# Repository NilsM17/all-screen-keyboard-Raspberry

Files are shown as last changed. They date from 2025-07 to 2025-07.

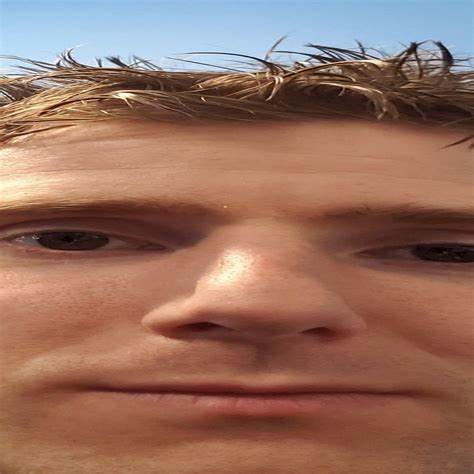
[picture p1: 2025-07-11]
keyboard/img/wide.jpeg

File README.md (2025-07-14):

# Working on Raspberry PI support
Since InkboxSoftware only worked with the Orange PI 5 and that one is way to expensive for my liking i will be working with an Raspberry PI 3 Model B as a replacement because thats what i have on hand (might upgrade to a PI 5 at some point)

# The open source all-screen keyboard
The first open source all-screen keyboard. This repository contains all the digital files used to produce the all-screen keyboard created by Inkbox Software in this video: 

## Future of the all-screen keyboard?
The goal of this project is to create a robust DIY guide for creating an all-screen keyboard. Currentyle there are a couple of software issues that need to be resolved, but more importantly the keys and frames themselves need to be remolded in order to make them more suitable for viewing and mass production. Members of the community are looking towards how to create a cheaper version out of some other material than 3D printed resin. Once we solve these issues, version 2 will be released to the public via this repository. 

## Could I still make my own today?
Well, you probably don't want to. As of today (2025/7/11) the keys are much too tall, and so not all the keys are able to be viewed at once. But for reference here is the list of hardware I used:
* Orange Pi 5 Ultra (any Orange Pi 5 could be a drop in replacement, well, you may have to change which pins you use)
* PCB found in this project's PCB folder
* Top Shell and keys printed in transparent resin
* Bottom shell printed in regular PLA (available as a single piece or multiple parts for printing at home)

Currently start up requires three steps, starting the python program, setting the bluetooth advertisement appearance, and then running the main keyboard program. 

### To enable SPI on the Orange Pi 5:

open **/boot/extlinux/extlinux.conf**

Add the following text
```
FDTOVERLAYS /dtbs/rockchip/overlay/rk3588-spi0-m2-cs0-cs1-spidev.dtbo
/dtbs/rockchip/overlay/rk3588-spi1-m1-cs0-spidev.dtbo
/dtbs/rockchip/overlay/rk3588-spi4-m2-cs0-spidev.dtbo
```

### Running the bluetooth python program:
Ensure you have the proper dependencies installed
```
cd keyboard
make py
```

### Starting bluetooth:
Setting the appearance to 961 will have the Pi show up as a keyboard. 
```
bluetoothctl 
discoverable on
pairable on
advertise on
menu advertise
appearance 961
```

### Starting the main keyboard program
Navigate to the directory
To build the program for the first time run
```
make build
```
Then run with
```
make run
```

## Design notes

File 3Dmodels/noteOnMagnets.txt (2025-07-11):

Magnet hole size notes:

magnets used are 5.0mm in diameter, but to fit them in plastic holes:
	5.2mm for tight fit (diameter)
	5.25 for a bit looser
	anything smaller and they won't go in
	anything larger and they fall out (5.3 sits well, but will fall out with a shake)
	recommend to use 5.25mm diameter holes
depth of hole should be 0.25mm + the height of the magnet

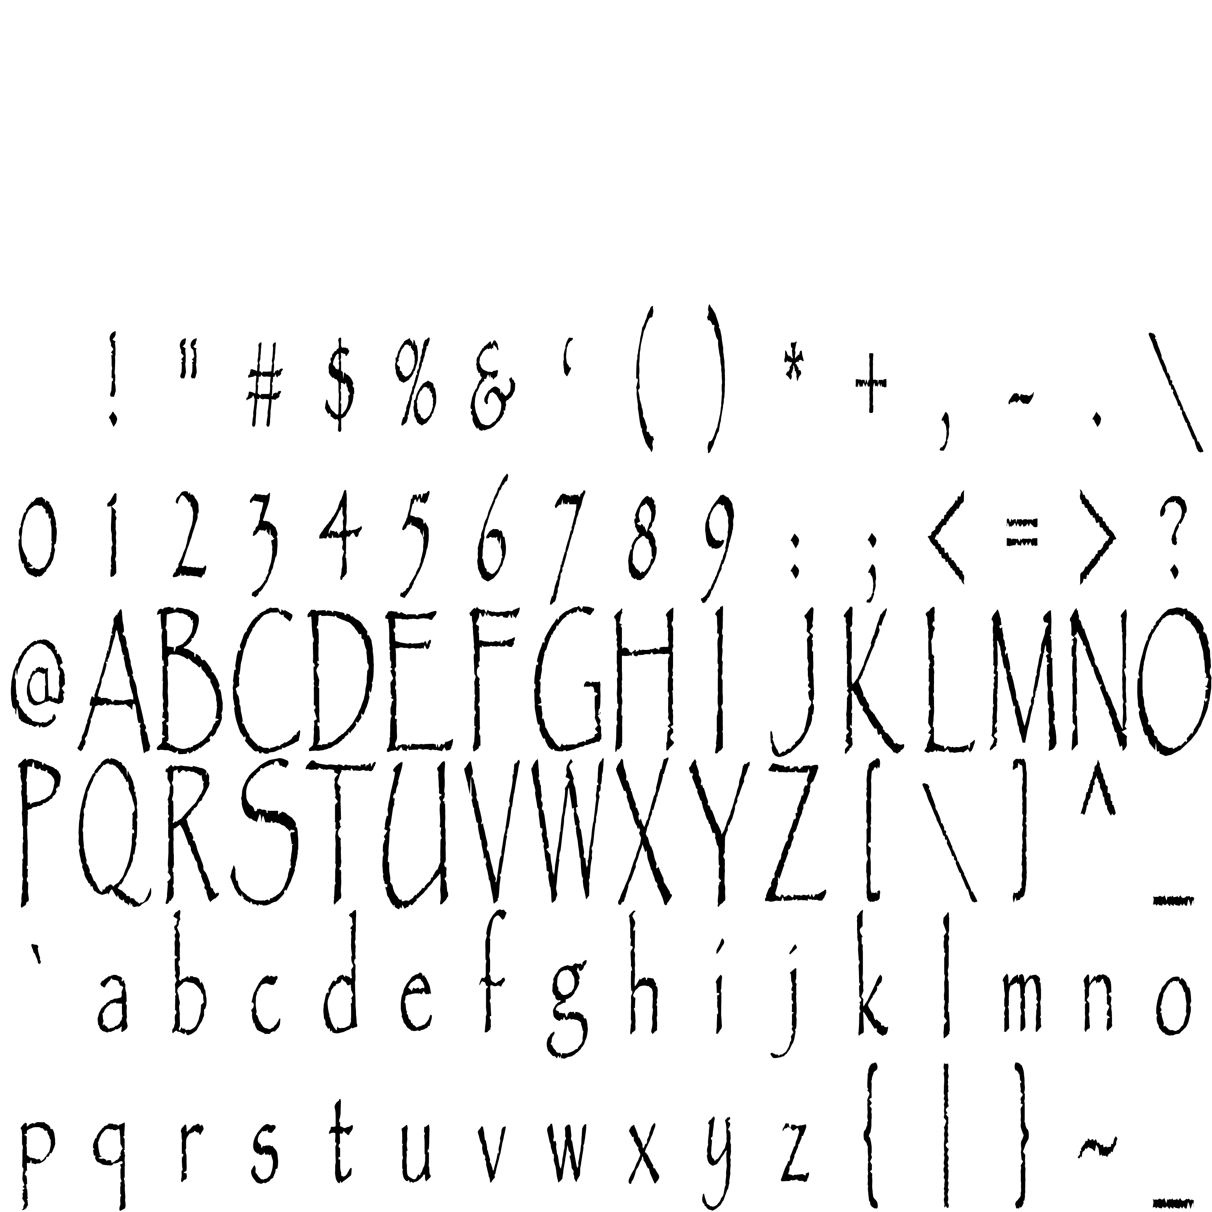
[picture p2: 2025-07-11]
keyboard/img/font2.png

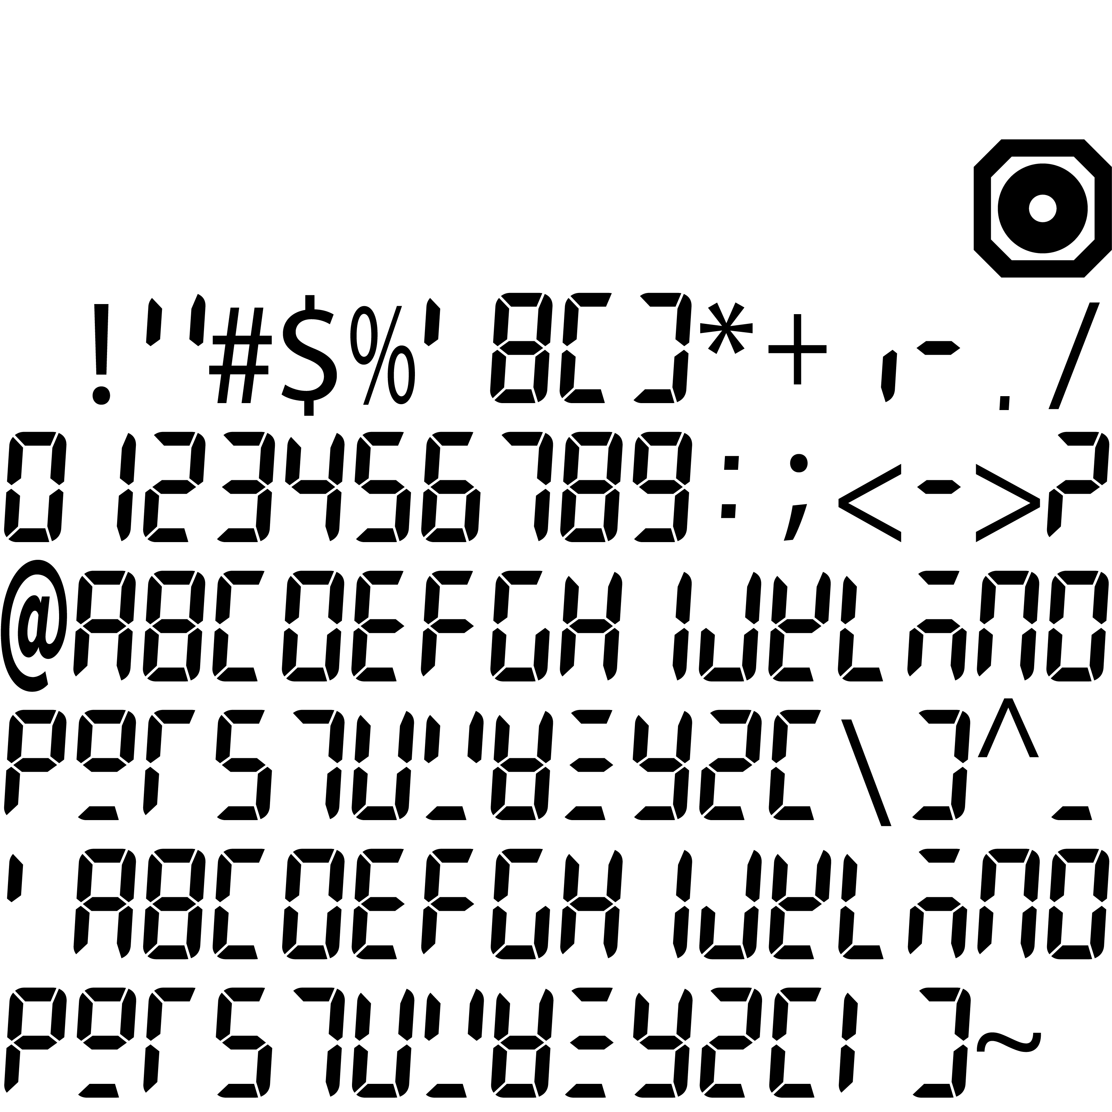
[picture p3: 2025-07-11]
keyboard/img/font.png

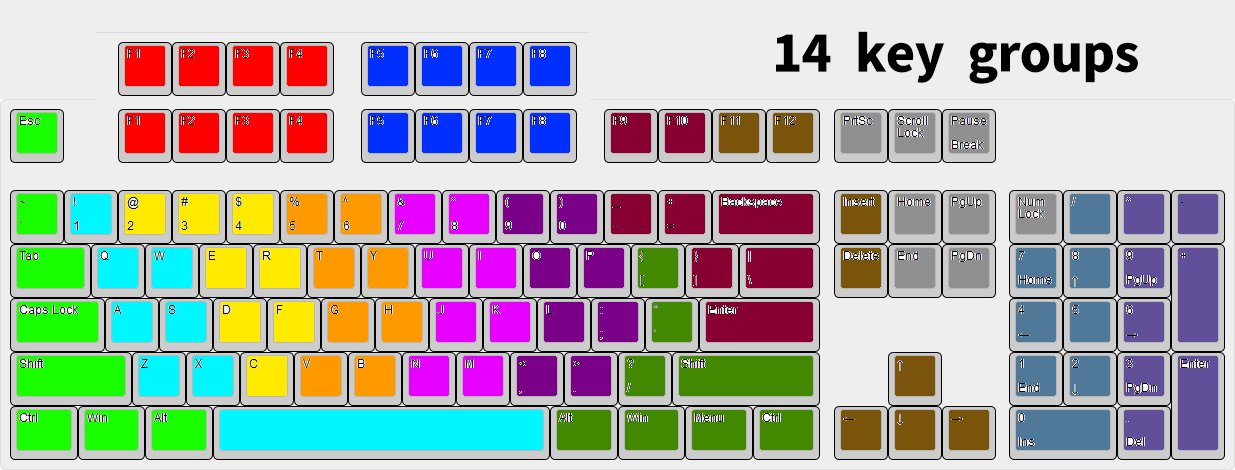
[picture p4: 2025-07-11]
PCB/keyboard-KiCad/keyGroupings.png

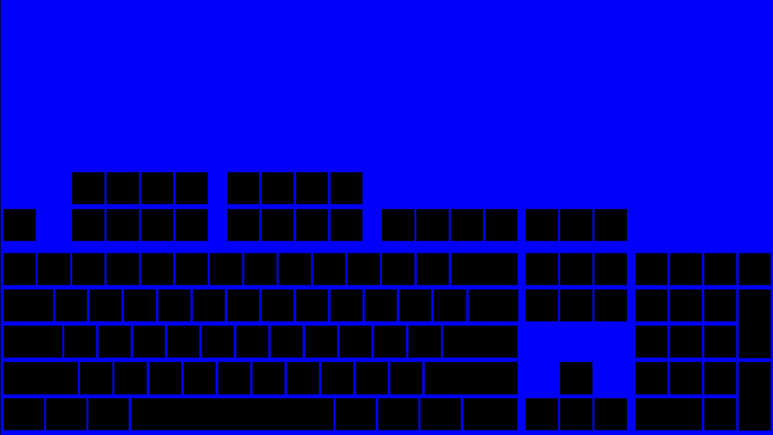
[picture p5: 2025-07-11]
reference images/blank layout.png

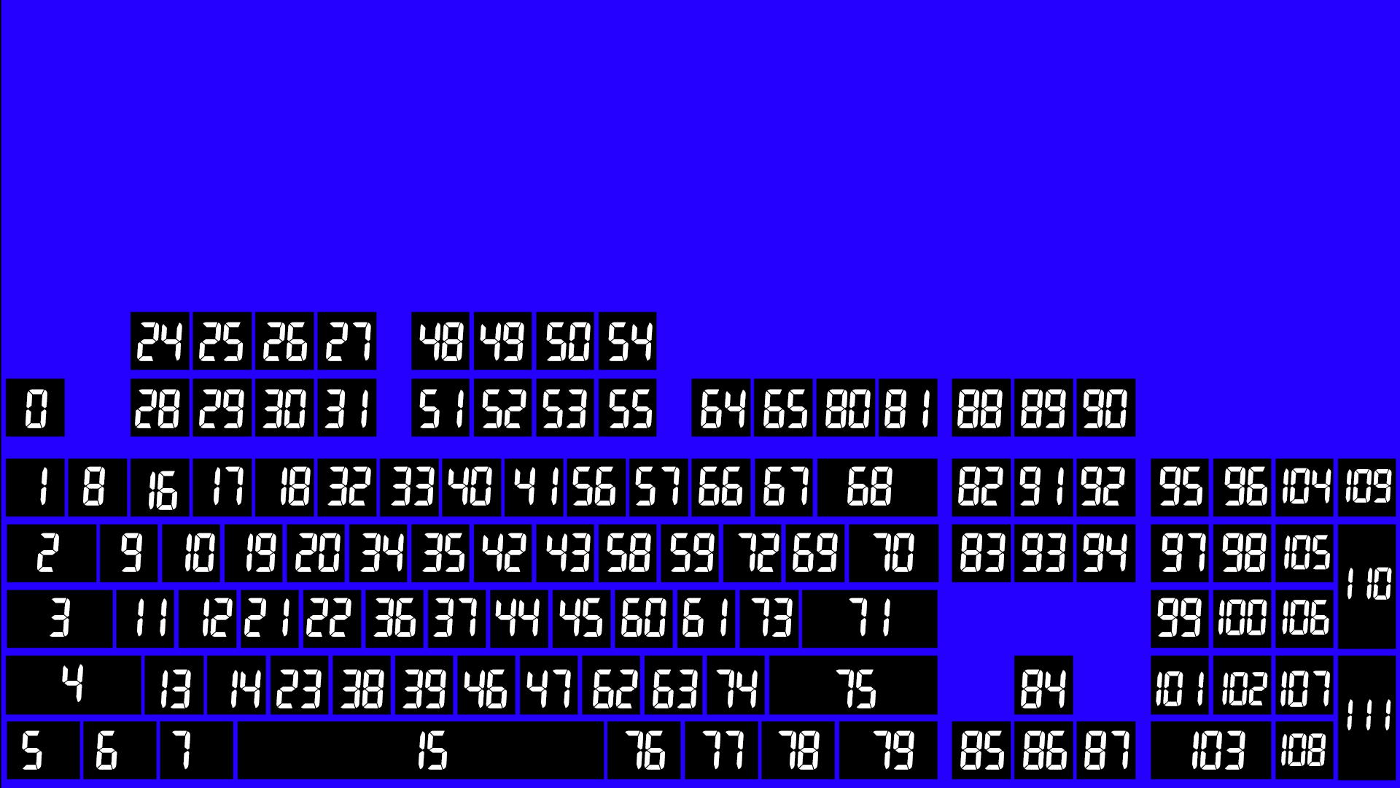
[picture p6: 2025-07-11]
reference images/layout.png

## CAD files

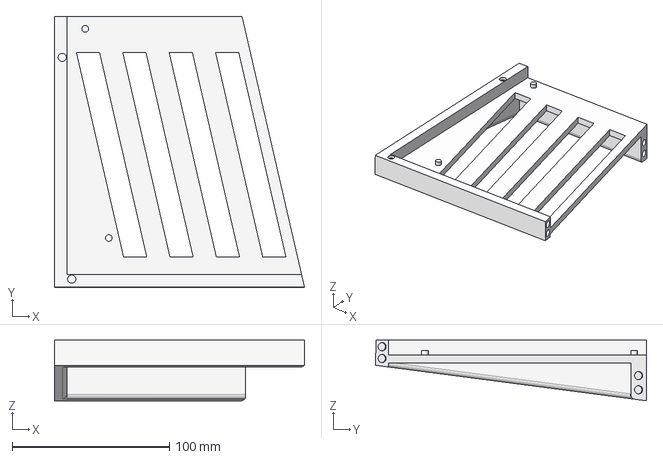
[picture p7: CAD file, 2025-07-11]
3Dmodels/case - multiple pieces/case0-0.step
159.1 x 172.3 x 38.5 mm

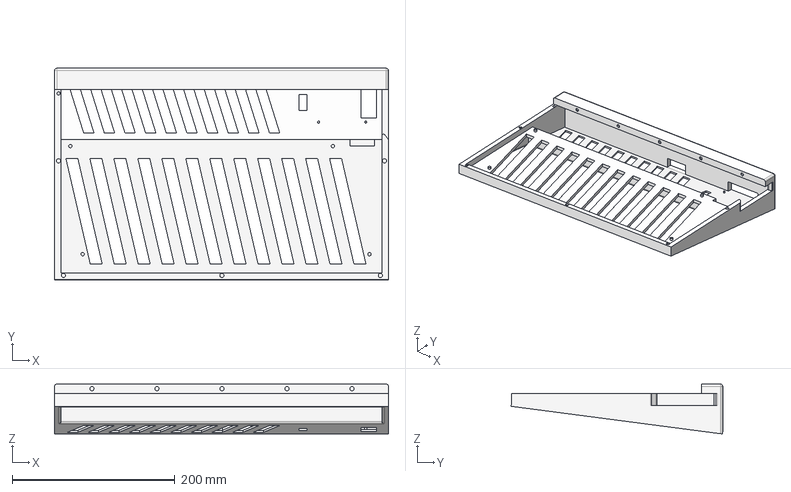
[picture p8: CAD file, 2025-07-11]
3Dmodels/case_onePiece.step
411.0 x 260.3 x 61.5 mm

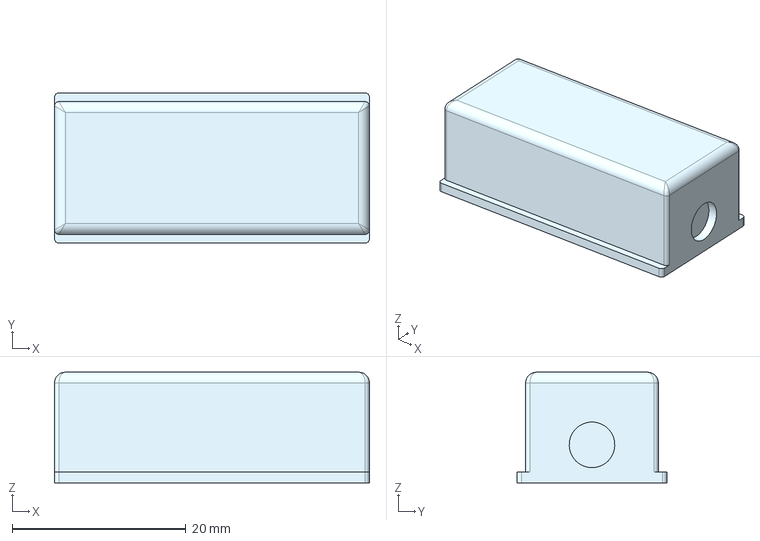
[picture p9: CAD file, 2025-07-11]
3Dmodels/individualkeys/key37.step
36.3 x 17.3 x 12.8 mm

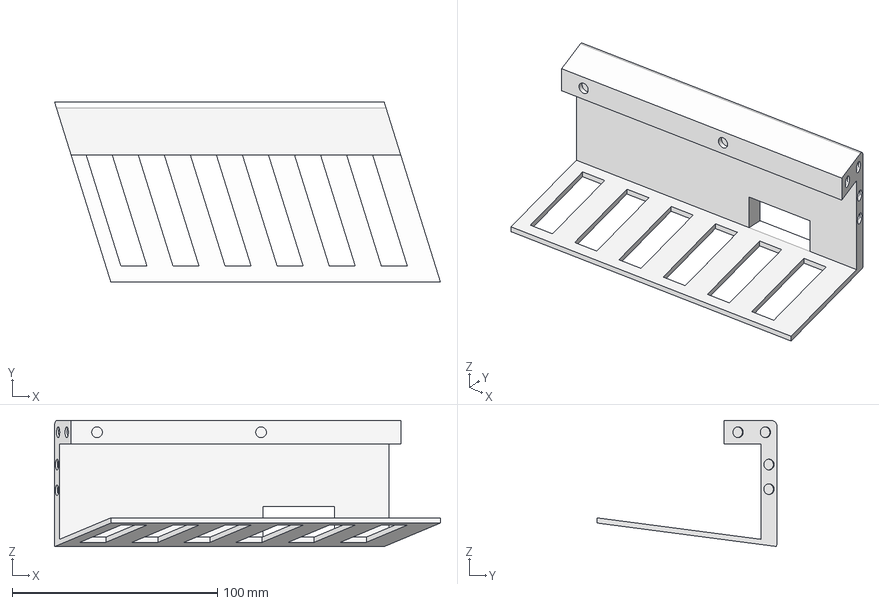
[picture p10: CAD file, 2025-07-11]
3Dmodels/case - multiple pieces/case1-1.step
188.2 x 88.0 x 61.5 mm

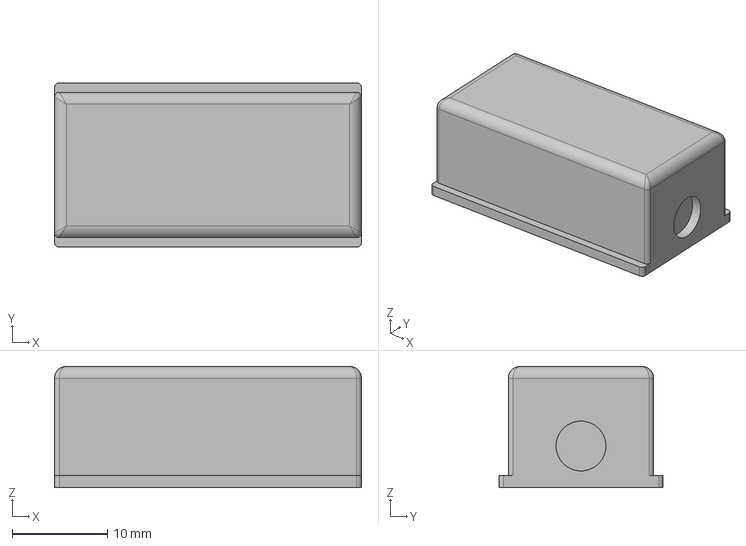
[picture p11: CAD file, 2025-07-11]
3Dmodels/individualkeys/key33.step
32.3 x 17.3 x 12.8 mm

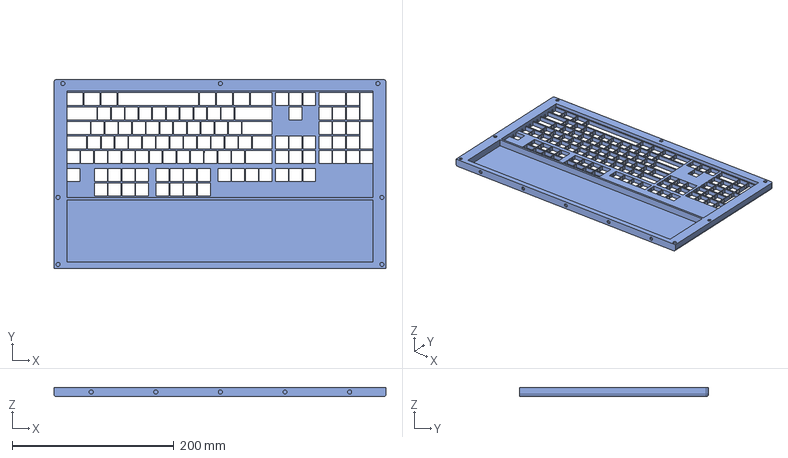
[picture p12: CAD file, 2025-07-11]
3Dmodels/topShell.step
411.0 x 234.0 x 11.5 mm

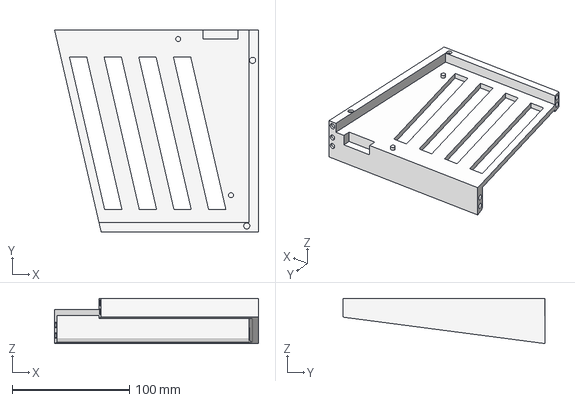
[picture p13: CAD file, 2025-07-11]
3Dmodels/case - multiple pieces/case0-2.step
173.7 x 172.3 x 38.5 mm

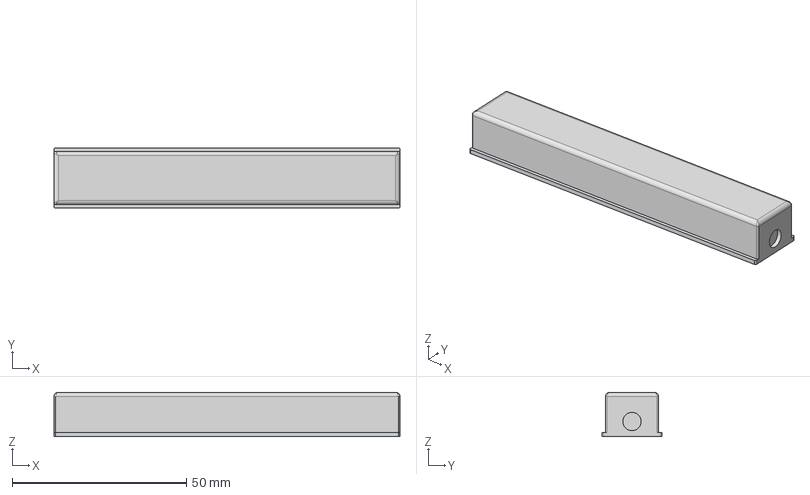
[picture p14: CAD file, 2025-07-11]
3Dmodels/individualkeys/keySpace.step
99.3 x 17.3 x 12.8 mm

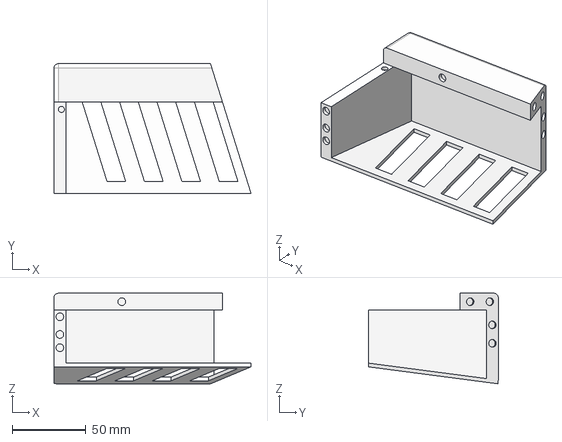
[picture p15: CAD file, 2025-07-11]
3Dmodels/case - multiple pieces/case1-0.step
133.8 x 88.0 x 61.5 mm

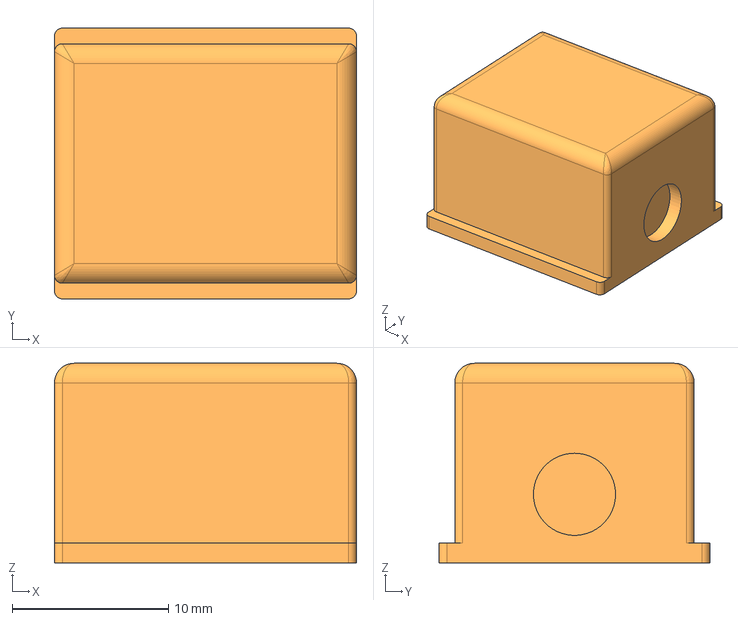
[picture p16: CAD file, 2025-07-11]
3Dmodels/individualkeys/key20.step
19.3 x 17.3 x 12.8 mm

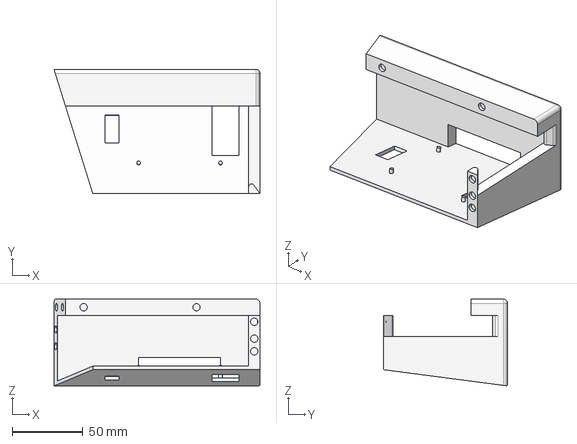
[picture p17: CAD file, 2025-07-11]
3Dmodels/case - multiple pieces/case1-2.step
146.0 x 88.0 x 61.5 mm

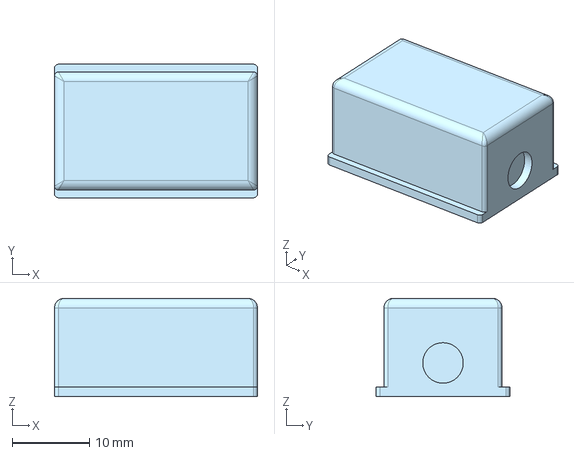
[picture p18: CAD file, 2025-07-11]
3Dmodels/individualkeys/key27.step
26.3 x 17.3 x 12.8 mm

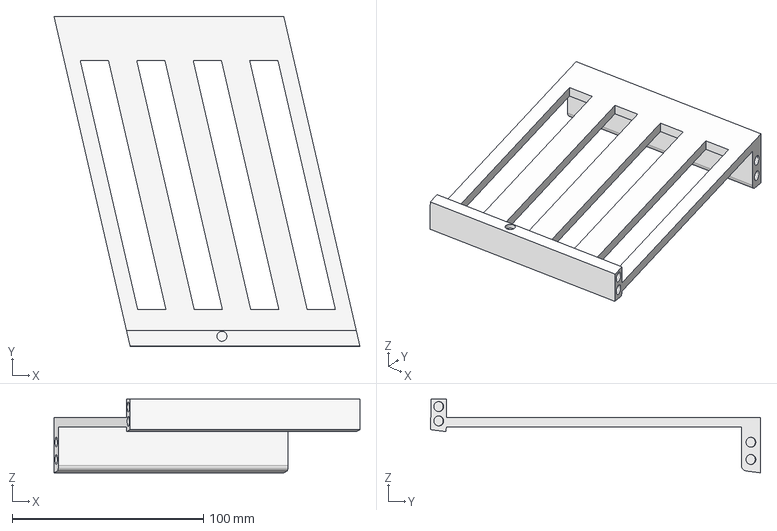
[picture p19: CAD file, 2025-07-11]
3Dmodels/case - multiple pieces/case0-1.step
159.8 x 172.3 x 38.5 mm

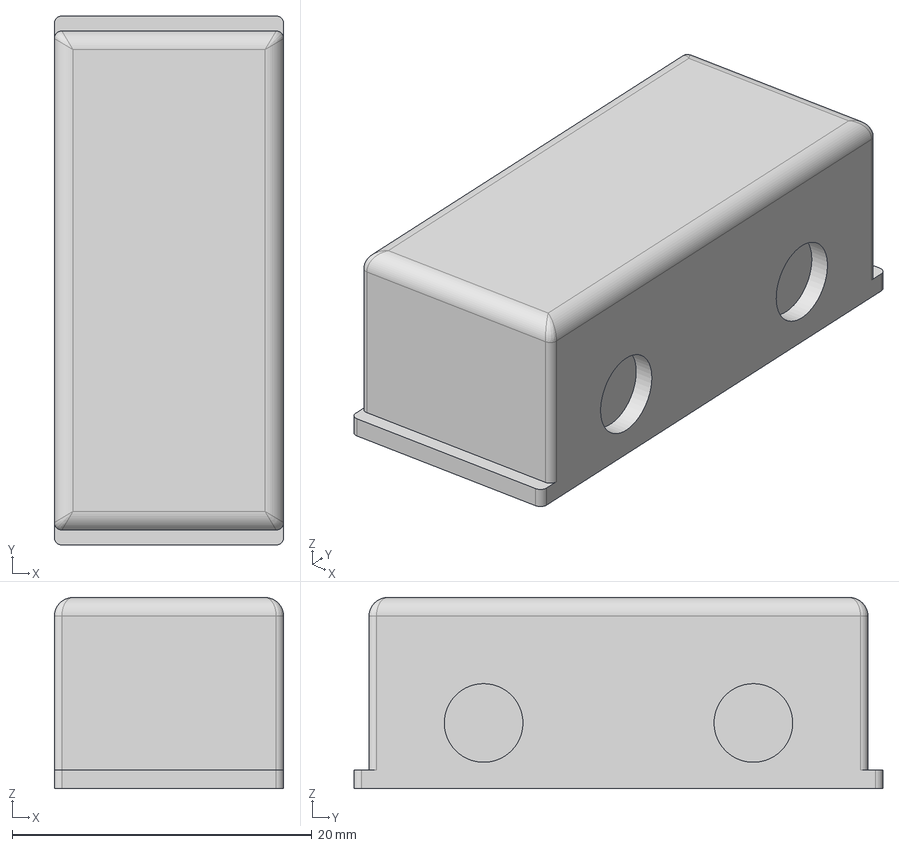
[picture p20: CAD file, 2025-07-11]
3Dmodels/individualkeys/key34.step
15.3 x 35.3 x 12.8 mm

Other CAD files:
3Dmodels/individualkeys/key29.step
3Dmodels/individualkeys/key24.5.step
3Dmodels/individualkeys/key46.step
3Dmodels/individualkeys/key16.step

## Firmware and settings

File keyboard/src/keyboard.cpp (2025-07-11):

//keyboard.cpp

#include "keyboard.h"

using namespace std;

#define CSp0 17
#define CSp1 20
#define CSp2 22
#define CSp3 25
#define SPIchannel 0
#define SPIspeed 500000



keyboard::keyboard(){
	keyboardWindow = new window();
	int OK = keyboardWindow->initialize(2560, 1440);
	//int OK = keyboardWindow->initialize(1920, 1080, false);
	if (OK != 0){
		printf("Error initializing window\n");
		return;
	}
	
	//get physical layouts:
	pl = new physicalLayout();
	vector<physicalLayout::keyRect> keyrects = pl->getPhysicalKeySizes();
	
	//initialize keys at locations
	if (keyrects.size() != MAXKEYS){
		printf("Error in number of keys initialized");
	}
	for (int i = 0; i < keyrects.size(); i++){
		keys.push_back({ i, {keyrects[i].x, keyrects[i].y, keyrects[i].w, keyrects[i].h}, -1, " " });	//no output
		cout << i << endl;
	}	
	
	//assign ID and location of initial 16 keys:
	/*
	int keySize = 96;
	int rowGap = 120 - keySize;
	int offsetX = 0;//2096;
	int offsetY = 0;//895;
		keys.push_back({ 0, {offsetX + (keySize + rowGap) * 1, offsetY, keySize, keySize}, 0, "/" });
		keys.push_back({ 1, {offsetX + (keySize + rowGap) * 2, offsetY, keySize, keySize}, 0, "*" });
		keys.push_back({ 2, {offsetX + (keySize + rowGap) * 3, offsetY, keySize, keySize}, 0, "-" });
		
		keys.push_back({ 3, {offsetX + (keySize + rowGap) * 3, offsetY + (keySize + rowGap) * 1, keySize, keySize*2 + rowGap}, 0, "+" });
		keys.push_back({ 4, {offsetX + (keySize + rowGap) * 2, offsetY + (keySize + rowGap) * 1, keySize, keySize}, 0, "9" });
		keys.push_back({ 5, {offsetX + (keySize + rowGap) * 1, offsetY + (keySize + rowGap) * 1, keySize, keySize}, 0, "8" });
		keys.push_back({ 6, {offsetX, offsetY + (keySize + rowGap) * 1, keySize, keySize}, 0, "7" });
		
		keys.push_back({ 7, {offsetX, offsetY + (keySize + rowGap) * 2, keySize, keySize}, 0, "4" });		
		keys.push_back({ 8, {offsetX + (keySize + rowGap) * 1, offsetY + (keySize + rowGap) * 2, keySize, keySize}, 0, "5" });
		keys.push_back({ 9, {offsetX + (keySize + rowGap) * 2, offsetY + (keySize + rowGap) * 2, keySize, keySize}, 0, "6" });
		
		keys.push_back({ 10, {offsetX + (keySize + rowGap) * 3, offsetY + (keySize + rowGap) * 3, keySize, keySize*2 + rowGap}, 0, "\n" });
		keys.push_back({ 11, {offsetX + (keySize + rowGap) * 2, offsetY + (keySize + rowGap) * 3, keySize, keySize}, 0, "3" });
		keys.push_back({ 12, {offsetX + (keySize + rowGap) * 1, offsetY + (keySize + rowGap) * 3, keySize, keySize}, 0, "2" });
		keys.push_back({ 13, {offsetX, offsetY + (keySize + rowGap) * 3, keySize, keySize}, 0, "1" });
		
		keys.push_back({ 14, {offsetX, offsetY + (keySize + rowGap) * 4, keySize*2 + rowGap, keySize}, 0, "0" });
		keys.push_back({ 15, {offsetX + (keySize + rowGap) * 2, offsetY + (keySize + rowGap) * 4, keySize, keySize}, 0, "." });
		*/
	
	return;
}

int keyboard::run(){
	//init bluetooth connection:
	bluetoothConn = new bluetooth();
	//run hall effect sensors
	bool keyboardActive = true;
	bool* on = &keyboardActive;
	
	loadProfile("eng");
	
	//run numpad profile initialization:
	
	//frame counter text:
		debugText.push_back(keyboardWindow->writeText("000", 100, 100, 2.0f, 0, 0, 0, 255));
	
	//debugging text:
	/*/
	debugTextOn = true;
	for (int i = 0; i < MAXKEYS; i++){
		debugText.push_back(keyboardWindow->writeText("000", keys[i].bounds.x + 25, keys[i].bounds.y + 40, 0.5f, 0, 0, 0, 255));
	}/**/
	
	/*/
	for (int i = 0; i < MAXKEYS; i++){
		rectKey(i, 0, 0, 0, 100, 1.0f, 1.0f);
		textureKey(i, 1, to_string(i), 1.0f, 1.0f);
	}
	/**/

/*	keyboardWindow->drawImage("img/wide.jpeg", 110, 10, 100, 100, 255);
	keyboardWindow->drawRect(10, 10, 100, 200, 255, 225, 0, 255);
	keyboardWindow->drawText("\u003F", 400, 10, 100, 200, 0, 0, 255, 255);
	assignKeyFont("img/HanyiSentyPagoda Regular.ttf"); 
	keyboardWindow->drawText("hello world", 300, 300, 250, 100, 0, 255, 0, 255);
	keyboardWindow->drawImage("img/wide.jpeg", 50, 50, 200, 100, 255);
	keyboardWindow->setbackrgoundColor(255, 0, 0, 255);
	keyboardWindow->setbackgroundImage("img/wide.jpeg");
	keyboardWindow->drawCircle(300, 380, 100, 6, 0, 255, 255, 255);
*/

	//run bluetooth interaction:
	thread bluetoothThread([this, on](){ bluetoothConn->begin(on, false); });	//true for testing, false for bluetooth on
	//run hall effect thread:
	thread hallEffectThread([this, on](){ runHallEffectSensors(on); });

	//keyboard monitor thread:
	thread monitorThread([this, on](){ keyboardMonitor(on); });

	//run graphics thread:
	keyboardWindow->runWindow(pressedKeys);	//graphics calls must run in main thread
	
	keyboardActive = false;	
	hallEffectThread.join();	//wait for hall effect polling to finish
	monitorThread.join();
	bluetoothThread.join();

	return 0;	//ends program
}
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

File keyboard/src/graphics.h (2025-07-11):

//graphics.h

//standard libraries
#include <stdio.h>
#include <iostream>
#include <vector>
#include <cmath>
#include <algorithm>
#include <fstream>
#include <thread>
#include <pthread.h>

//graphics libraries
#include <GLES3/gl3.h>
#include <SDL2/SDL.h>
#include <SDL2/SDL_opengles2.h>

//for video
extern "C" {
#include <libavcodec/avcodec.h>
#include <libavformat/avformat.h>
#include <libswscale/swscale.h>
}

//custom libraries
#include "shader.h"
#include "texture.h"
#include "text.h"

#define FORNORMALTEXTURE 512
#define FORSHIFTTEXTURE 1024
#define FORCTRLTEXTURE 2048
#define FORALTTEXTURE 4096
#define FORFNTEXTURE 8192

class window{
	
public:
	int initialize(int windowWidth, int windowHeight, bool fullscreen = true);
	int runWindow(bool* pressedKeys);

	//drawing functions:
	int drawRect(int x, int y, int width, int height, int r, int g, int b, int a, int keyID=-1);
	int drawCircle(int centerX, int centerY, int radius, int segments, int r, int g, int b, int a, int keyID=-1);

	int setFont(const char* fontName);	
	int drawText(const char* text, int x, int y, int width, int height, int r, int g, int b, int a, int keyID=-1);
		//text will appear in squished into this box

	//drawImage
	int drawImage(const char* src, int x, int y, int width, int height, int a, int keyID=-1);

	//writeText
	text* writeText(const char* inputText, int x, int y, float size, int r, int g, int b, int a);
		/*function that creates a textObj, which is a class that holds a vector of rects, and a sttring, location, color, etc.
			//returns the handle for the textObj so that you can use textObj.updateText(strring input) to update text
			//uses the built in font texture from the src folder, src/defaultText			
			//only support ascii under 128
		*/			
	int deleteText(text* toRemove);
		//removes text from rendering list


	//set background
	int setbackgroundImage(const char* src);
	void clearbackgroundImage();
	void setbackrgoundColor(int r, int g, int b, int a);
		//if called after set background image, will clear the image

	//only supports 1 video right now
	int loadVideo(const char* filename, int x, int y, int w, int h);

	//load shaders:
	int loadCustomShaderProgram(const char* vertexShaderFilename, const char* fragmentShaderFilename, int type);
		#define TYPE_PRESS_TEXTURE_SHADER 0
		#define TYPE_TEXTURE_SHADER 1
		#define TYPE_OTHER_SHADER 2
	//clear:
	void clearGraphicsMemory();
		//reset all vector lists, vram VAO and VBO, texture count var, reset pressShaderProgram
		
	//locking graphics:
	void setGraphicsLock(bool lockState);	//graphics will not render if lock set to true
	
	//multithreaded functions since graphics calls must be made in main thread:
	void requestClear();
	bool asyncFunctionCompleted();
	int asyncOutput();
	void requestCustomShader(const char* vertexShaderFilename, const char* fragmentShaderFilename, int type);
	void requestDrawRect(int x, int y, int width, int height, int r, int g, int b, int a, int keyID=-1);
	void requestSetbackgroundImage(const char* src);
	void requestDrawCircle(int centerX, int centerY, int radius, int segments, int r, int g, int b, int a, int keyID=-1);
	void requestDrawText(const char* text, int x, int y, int width, int height, int r, int g, int b, int a, int keyID=-1);
	void requestDrawImage(const char* src, int x, int y, int width, int height, int a, int keyID=-1);
	bool isRendering();
	
private:
		//multithread variables: (move these down to private later)
		bool asyncToDo = false;
		bool needToClear = false;
		int asyncOutputValue = -1;
		bool needCustomShader = false; const char* vertexShaderFileNameREQ; const char* fragmentShaderFilenameREQ; int typeREQ; 
		bool needDrawRect = false; int xREQ; int yREQ; int widthREQ; int heightREQ; int rREQ; int gREQ; int bREQ; int aREQ; int keyIDREQ=-1;
		bool needSetBackground = false; const char* srcREQ;
		bool needDrawCircle = false; int centerXREQ; int centerYREQ; int radiusREQ; int segmentsREQ;
		bool needDrawText = false; const char* textREQ;
		bool needDrawImage = false;
		
		
	int windowWidth = 640;
	int windowHeight = 480;
	
	bool graphicsLock = false;
	bool currentlyRendering = false;
	
	struct rectangle{
		float x;
		float y;
		float x2;
		float y2;
	};
	struct color{
		float r;
		float g;
		float b;
		float a;
	};
	struct order{
		//int absoluteOrder;	this is just the index of the item in the vector
		int listType;				//0 = vectorShape, 1 = vectorCircle, 2 = vectorText/vectorImage
		unsigned int relativeIndex;	//index in the above vector
		int keyTieID;				//keyID of relevant key, default -1
		int keyHeldType;			//-1 if no keyHeld types for key, else defines the current key down type
	};
	#define VECTORSHAPETYPE 0
	#define VECTORCIRCLETYPE 1
	#define VECTORTEXTIMAGETYPE 2
	#define PRESSEDTEXTURESHADERTYPE 100
	rectangle createRectangle(int x, int y, int width, int height);
	std::vector<GLfloat> generateCircleVerticies(int cx, int cy, int r, int numSegments);
	color createColor(int r, int g, int b, int a);

	//zorder list
	std::vector<order> zorderList;
	
	//for key down texture switching
	bool shiftHeld = false;
	bool ctrlHeld = false;
	bool altHeld = false;
	bool fnHeld = false;
	bool capsOn = false;
	int setHeldType(int keyID);	//returns the heldType for the order struct, checks all keys to determine if key has multiple textures for held type
	bool isALetterKey(int keyID);

	//list of solid color shapes:
	std::vector<GLuint> vectorShapeGLuint;
	std::vector<GLuint> vectorCircleuint;
		std::vector<int> vectorCircleSegments;	//number of triangles in each circle
	//list of image and text shapes:
	std::vector<GLuint> vectorTextGLuint;
	std::vector<GLuint> vectorTextures;

	const char* currentFont;
	color clearColor;
	GLint textureSamplerUniformLocation;
	int backgroundImgIndex = 0;
	bool backgroundImageOn = false;

	//video:
	const int VIDEOFRAMEBUFFERSIZE = 60;
	GLuint videoVerticies;
	GLuint videoTexture = -1;
	std::vector<SDL_Surface*> videoSurfaceBuffer;
	bool videoStarted = false;
	
	const char* videoFilename;
	bool videoReady = false;
	void playVideo();
	int fCount = 0;
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
